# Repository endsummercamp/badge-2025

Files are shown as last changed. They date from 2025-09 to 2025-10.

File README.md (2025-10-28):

# badge-2025

Repository containing the schematics for the flex PCB badge distributed at ESC{21}.

The schematics are licensed under the CERN OHL S v2 license.

The badge has been designed by [Jacopo Franco](https://www.jacopofranco.com/), that we thank for the effort in making this literal show of force a reality ;)

Special thanks to [Kezi](https://github.com/Kezii), [Kowalski](https://github.com/kowalski7cc), [K3lite](https://github.com/k3lite) & [Baobots](https://github.com/baobots) for the efforts spent into debugging & flashing all of them during the camp.

And for going the extra mile and designing a custom case that solves many assembly issues, a very felt thanks to [k0bld](https://github.com/k0bld).

<video src="https://github.com/user-attachments/assets/acb0492f-e134-4207-b74a-9145ce9de10b"
       autoplay
       loop
       muted
       playsinline
       width="600">
  Your browser does not support the video tag.
</video>

---

# Badge Instructions

## Assembly

* The badge must be folded into position.
* To keep it fixed, we recommend using **UV glue**, **superglue**, or **thin double-sided tape**.
* **Do not solder directly** onto the PET substrate — this is very challenging, even with bismuth low-temperature solder.

## Flashing
**USB communication is not supported** — the port is for charging only.
To flash the badge the first time, make use of the UART and the power pins as below.




### USB-C Connector

* The USB-C must also be folded.
* Align the tab with the solid line located after the resistors.
* With the **copper contacts facing outward**, insert the connector into a male USB Type-C cable.


---

## Charging
* There are no LEDs to indicate charging progress. The charger is however guaranteed to fully charge the battery in 2.5h. The battery is fully protected and the charger has multiple overcurrent, overvoltage and temperature protections. It can trickle-charge.
* Battery life is approximately 4h with the "All sides music" profile and the WiFi radio at 8.5dBm.
* An **interrupt pin** connected to the charger will change state during charging. You will have to implement it yourself.

---

## Firmware

* The badge ships with the **WLED firmware** by default.
* * Firmware updates can be done via **WLED OTA** or the **Serial pads**.
* To connect:

  1. Connect to the Wi-Fi network:

     ```text
     SSID: wled-ap  
     Password: wled1234
     ```
  2. Open the address in your browser:

     ```text
     4.3.2.1
     ```

---

## Pinout

```text
Charger status:       GPIO 10
Battery voltage:      Analog GPIO 3 (divider only enabled when LED MOSFET is ON)
LEDs MOSFET:          GPIO 4
LED data:             GPIO 8
I²C SDA:              GPIO 7
I²C SCL:              GPIO 6
Touch button 1:       GPIO 0
Touch button 2:       GPIO 1
```

---

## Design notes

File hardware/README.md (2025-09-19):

ESC 2025 Badge

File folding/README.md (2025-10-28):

# Folding Instructions for the BadgESC{21} Badge

These are the instructions for folding the **BadgESC{21} Badge** into its final cube shape.
Use a **plastic card** or another thin, flat object to achieve tight bends on the PET plastic substrate. It may also be possible to mold the shape by gently warming the material, although this method has not been tested.

To secure the folded parts, use **UV glue**, **superglue**, or another strong adhesive.

---

## Step 1: Initial Positioning

PXL\_20251021\_200502498

1. Place the badge on a flat surface with the components **facing up**.
2. Bend the **USB connector flap** by aligning its edge with the **solid white line** located near the set of **small resistors**, **not** the large ones.
3. The large resistors are not connected to any circuit. They are present only to provide structural thickness for engaging the USB Type-C connector’s locking mechanism.

---

## Step 2: Power Switch and Battery Test

PXL\_20251021\_200546398

1. Ensure the **power slide switch** lever is positioned **outside the white silkscreen**, which indicates the badge is powered **off**.
2. Insert the battery and briefly **test the badge** by toggling the power switch.

---

## Step 3: Preparing for Folding

PXL\_20251021\_201041561
PXL\_20251021\_201408873

1. **Remove the battery** before proceeding.
2. Begin folding the badge along the **solid silkscreen lines** using a **flat, thin piece of plastic** to help create sharp bends.

---

## Step 4: Folding the Top

PXL\_20251021\_201714334

Continue folding the upper section of the badge carefully, ensuring all edges align properly.

---

## Step 5: Gluing the Structure

PXL\_20251021\_203347326

This is the most delicate part of the assembly.
Apply **small drops of glue** to the sides while maintaining the cube shape. You can use your **fingers** or **tape** to hold the parts in place while the glue sets.

---

## Step 6: Final Assembly

PXL\_20251028\_121333355

After the glue cures, the badge should form a stable cube-like structure as shown above.

Your **BadgESC{21} Badge** is now ready for use.

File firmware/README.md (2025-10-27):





The badge USB is physically unstable because of very tight tolerances in the port.
Please notice the points used to flash the badge in the picture above. You will need some thin-tip probes.

The .bin file is all you need. It's a 1:1 dump of the internal memory, containing WLED and all its settings. Feel free to flash it and then recompile a fresh new version.

## How to flash the first time
Go into the legacy directory, download the bin, then using esptool:
```
esptool.py --port=/dev/ttyUSB0 write-flash 0x0 backup.bin
```

---

# Recompiling the Firmware for BadgESC{21}

If you wish to recompile the WLED firmware yourself to customize features or update configurations, follow the instructions below.

## Steps to Recompile

1. Open the official WLED Web Compiler:
   [https://wled-compile.github.io/](https://wled-compile.github.io/)

2. Click **Load configuration from a file**.

3. From your computer, select the configuration file:
   `WLED_compile_dd_mm_yyyy_BadgESC{21}.json`

4. Click **Regenerate** to rebuild the firmware using the provided configuration.

5. After regeneration, you may customize and compile your firmware as required.

After compilation, download the resulting `.bin` file and flash it to your device following the standard WLED installation procedure.

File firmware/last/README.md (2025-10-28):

# 🔧 Flashing and Configuring WLED Firmware for BadgESC{21}

## 1. Flashing Firmware

First, flash the `.bin` file:

Flashing firmware example

---

### 1.1 Connect to Access Point (AP)

Since the firmware does not yet have your Wi-Fi credentials, the badge will create its own access point (AP).
Connect to it using the following information:

* **SSID:** `WLED-AP`
* **Password:** `wled1234`

---

## 2. Upload Configuration

Once connected to the device, find its IP address and navigate there.

1. At the top of the page, click **Config** → **Security & Updates**.
2. Scroll down until you reach **Backup & Restore** and **Restore presets**.
3. Upload the preset file:

   * `wled_presets_BadgESC{21}.json`
     *(Be sure to press **Upload** after selecting the file.)*
4. Next, in the **Restore configuration** section, select and upload the file:

   * `wled_cfg_BadgESC{21}.json`
5. Wait approximately **10 seconds**, then **toggle the power switch** to perform a full reboot.

---

### 2.1 Reconnect and Final Setup

After rebooting:

1. Reconnect to the Access Point `WLED-AP`.
2. 🔗 **[http://badgesc.local](http://badgesc.local)**
3. Navigate again to **Config → Wi-Fi Setup**.
4. Enter your local Wi-Fi network credentials to connect the badge to your home network.

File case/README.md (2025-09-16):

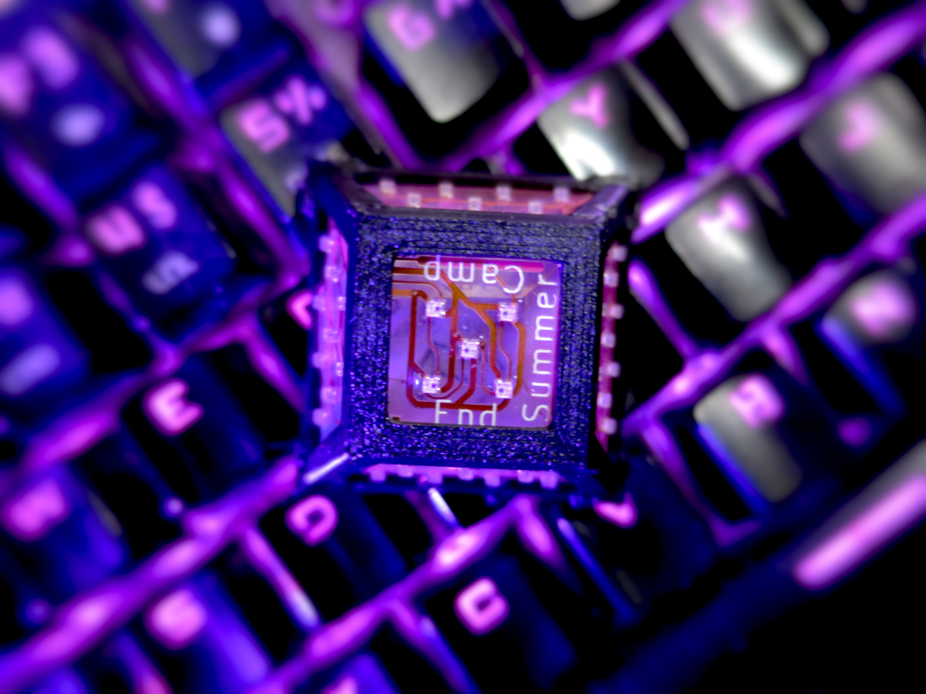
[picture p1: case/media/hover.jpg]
hover


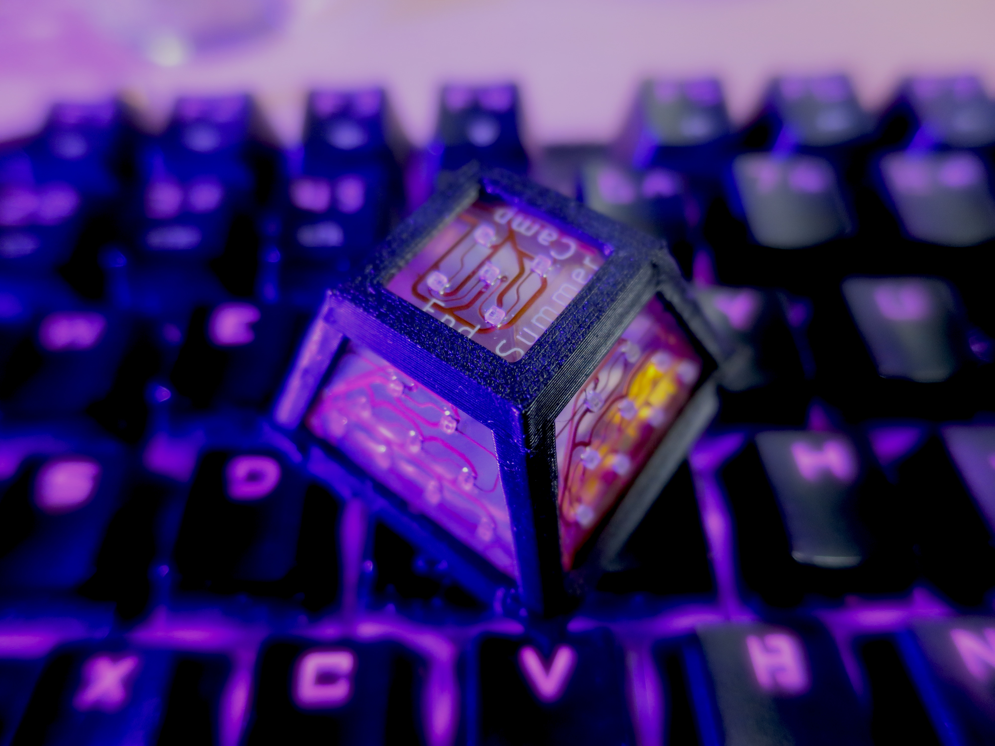
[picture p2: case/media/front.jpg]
front


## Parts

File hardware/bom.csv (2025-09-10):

Designator | Footprint | Quantity | Value | LCSC Part #
ANT2 | ANT-SMD_6P-L1.6-W0.8-P1.20-1 | 1 | ANT016008LCS2442MA | C76585
C1, C2, C3, C4 | CAP-SMD_BD4.0-L4.3-W4.3-LS5.1-FD | 4 | 126RV0140
C11, C12, C19, C9 | 0603 | 4 | 10uF
C13, C15, C20, C21, C7 | 0402 | 5 | 100nF
C14, C16, C23, C24, C31, C5, C8 | 0402 | 7 | 2.2uF
C17 | 0402 | 1 | 2.2uF | C12530
C18, C22 | 0402 | 2 | 15pF | C1548
C25 | 0402 | 1 | 10nF | C15195
C26 | 0402 | 1 | 100nF | C1525
C27 | 0402 | 1 | 1.1pF | C88920
C28 | 0402 | 1 | 2.3pF | C2190124
C6 | 0402 | 1 | 10nF
CN1 | CONN-SMD_2P-P1.20_781710002 | 1 | 781710002 | C505023
L1 | 0402 | 1 | 2.0nH | C76769
L4 | 0402 | 1 | 24nH | C404641
LED1, LED10, LED11, LED12, LED13, LED14, LED15, LED16, LED17, LED18, LED19, LED2, LED20, LED21, LED22, LED23, LED24, LED25, LED26, LED27, LED28, LED29, LED3, LED30, LED31, LED32, LED33, LED34, LED35, LED36, LED37, LED38, LED39, LED4, LED40, LED41, LED42, LED43, LED5, LED6, LED7, LED8, LED9 | LED-SMD_4P-L1.0-W1.0-TL_XL-1010RGBC-WS2812B | 43 | XL-1010RGBC-WS2812B
Q1 | SOT-23 | 1 | CJ3407 | C15903
Q2 | SOT-723 | 1 | SSM3K15AMFV,L3F(T
R1, R11, R2, R3, R5, R6 | 0402 | 6 | 5.1k | C25905
R10, R14, R21, R23, R4, R8 | 0402 | 6 | 100k | C25741
R13, R17, R18, R19, R20, R25 | 0603 | 6 | 49.9r | C23185
R16, R7, R9 | 0402 | 3 | 10k | C25744
SW1 | SW-TH_MSK12C02 | 1 | MSK12CO2-SZ
U1 | LGA-12_L2.0-W2.0-P0.50-BL | 1 | LIS2DH12TR
U2 | SOT-23-5_L2.9-W1.6-P0.95-LS2.8-TL | 1 | LGS4084HB5-4.35 | C20618071
U3 | QFN-32-1EP_5x5mm_P0.5mm_EP3.45x3.45mm | 1 | ESP32-C3 | C2858491
U4 | SOT-23-5_L3.0-W1.7-P0.95-LS2.8-BR | 1 | LW5233A23E | C20630437
U5 | SENSOR-SMD_ICS-43432 | 1 | ICS-43432 | C574021
Y1 | Crystal_SMD_2016-4Pin_2.0x1.6mm | 1 | 40MHz 10ppm 8pf | C2835990

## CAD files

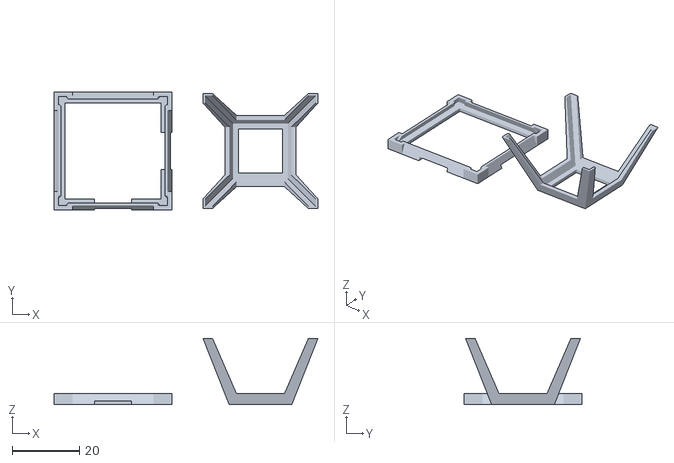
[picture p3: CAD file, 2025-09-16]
case/badge_case.stl
78.8 x 35.2 x 19.8

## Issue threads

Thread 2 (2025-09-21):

PCB assembly quality control not passed

Blaster1920, 2025-09-21:
We noticed an high amount of failures among the badges.
Upon inspection, at least a whole panel has been soldered with a subpar quality.
Follow pictures under the microscope.

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

Blaster1920, 2025-09-21:
The X-Ray views provided by JLC focusing on the accelerometer package.

[1.bmp](https://github.com/user-attachments/files/22453529/1.bmp)
[2.bmp](https://github.com/user-attachments/files/22453521/2.bmp)
[3.bmp](https://github.com/user-attachments/files/22453525/3.bmp)
[4.bmp](https://github.com/user-attachments/files/22453530/4.bmp)
[5.bmp](https://github.com/user-attachments/files/22453528/5.bmp)
[6.bmp](https://github.com/user-attachments/files/22453527/6.bmp)
[7.bmp](https://github.com/user-attachments/files/22453524/7.bmp)
[8.bmp](https://github.com/user-attachments/files/22453526/8.bmp)
[9.bmp](https://github.com/user-attachments/files/22453522/9.bmp)
[10.bmp](https://github.com/user-attachments/files/22453523/10.bmp)

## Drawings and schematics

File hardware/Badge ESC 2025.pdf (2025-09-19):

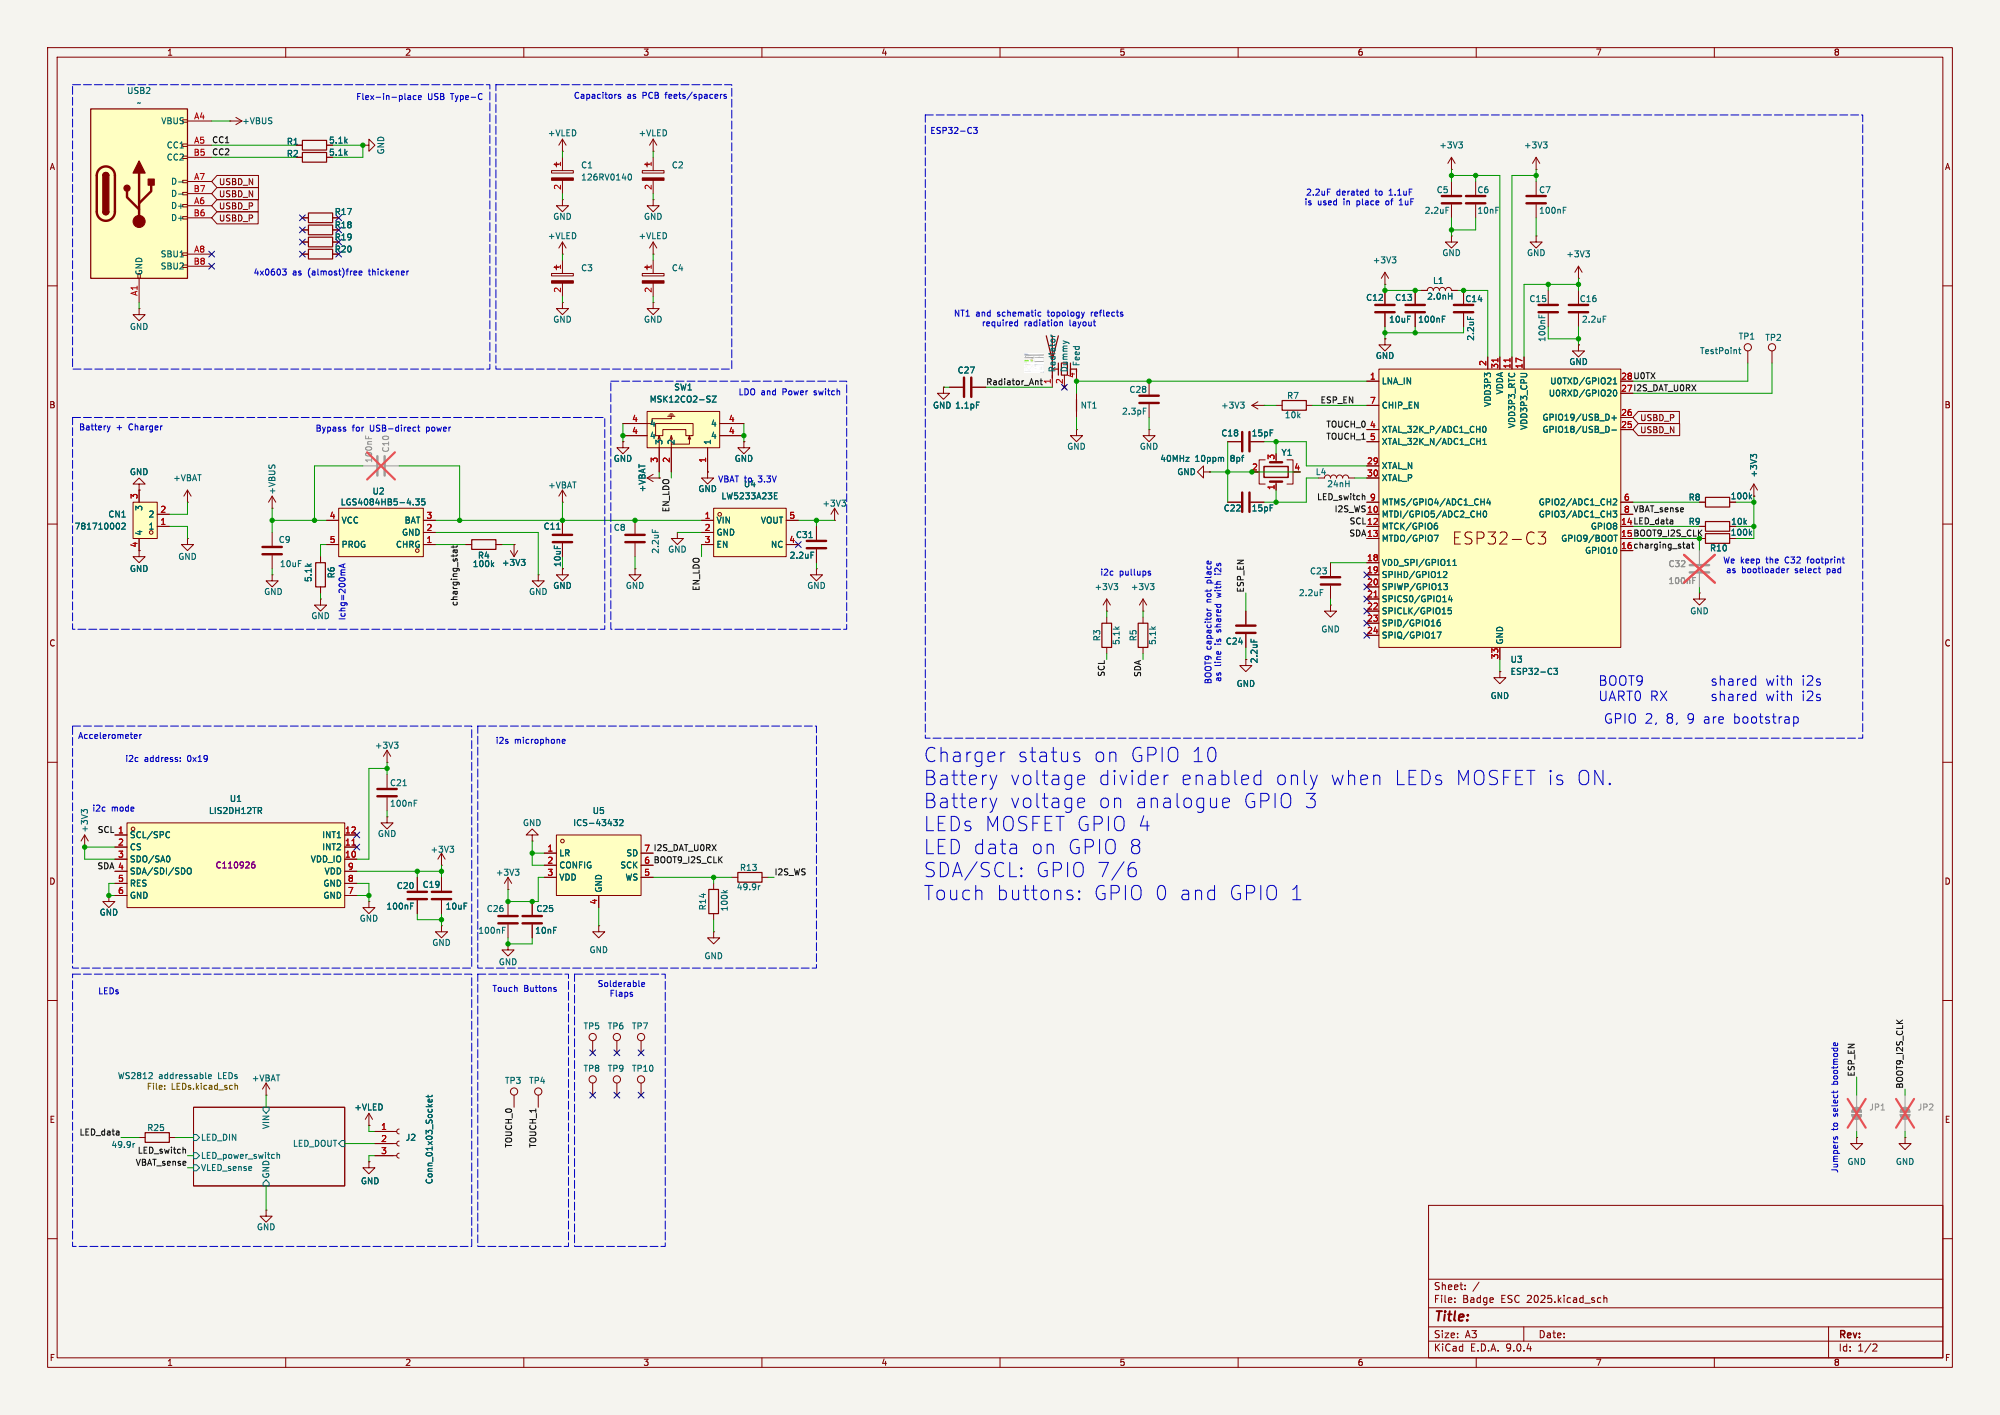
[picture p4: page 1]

1 2 C3 GND GND GND A1 VBUS A4 CC1 A5 CC2 B5 D- A7 D- B7 D+ A6 D+ B6 SBU1 A8 SBU2 B8 USB2 ~

2 VDDA 31 GND 33 VDD3P3_RTC 11 VDD3P3_CPU 17 U0TXD/GPIO21 28 U0RXD/GPIO20 27 GPIO19/USB_D+ 26 GPIO18/USB_D- 25 GPIO2/ADC1_CH2 6 GPIO3/ADC1_CH3 8 GPIO8 14 GPIO9/BOOT 15 GPIO10 16 U3ESP32-C3 +VBAT GND R14 100k

2 VDDA 31 GND 33 VDD3P3_RTC 11 VDD3P3_CPU 17 U0TXD/GPIO21 28 U0RXD/GPIO20 27 GPIO19/USB_D+ 26 GPIO18/USB_D- 25 GPIO2/ADC1_CH2 6 GPIO3/ADC1_CH3 8 GPIO8 14 GPIO9/BOOT 15 GPIO10 16 GND GND GND GND

4 SD 7 SCK 6 WS 5+VBAT GND GND GND U4
J2 Conn_01x03_Socket 1

Battery voltage divider enabled only when LEDs MOSFET is ON.
Battery voltage on analogue GPIO 3
LEDs MOSFET GPIO 4
LED data on GPIO 8
SDA/SCL: GPIO 7/6
Touch buttons: GPIO 0 and GPIO 1

SCL/SPC 1 CS 2 SDO/SA0 3 SDA/SDI/SDO 4 RES 5 GND 6
INT2 11 VDD_IO 10 VDD 9 GND 8 GND 7 GND

C110926 SCL/SPC 1 CS 2 SDO/SA0 3 SDA/SDI/SDO 4 RES 5 GND 6

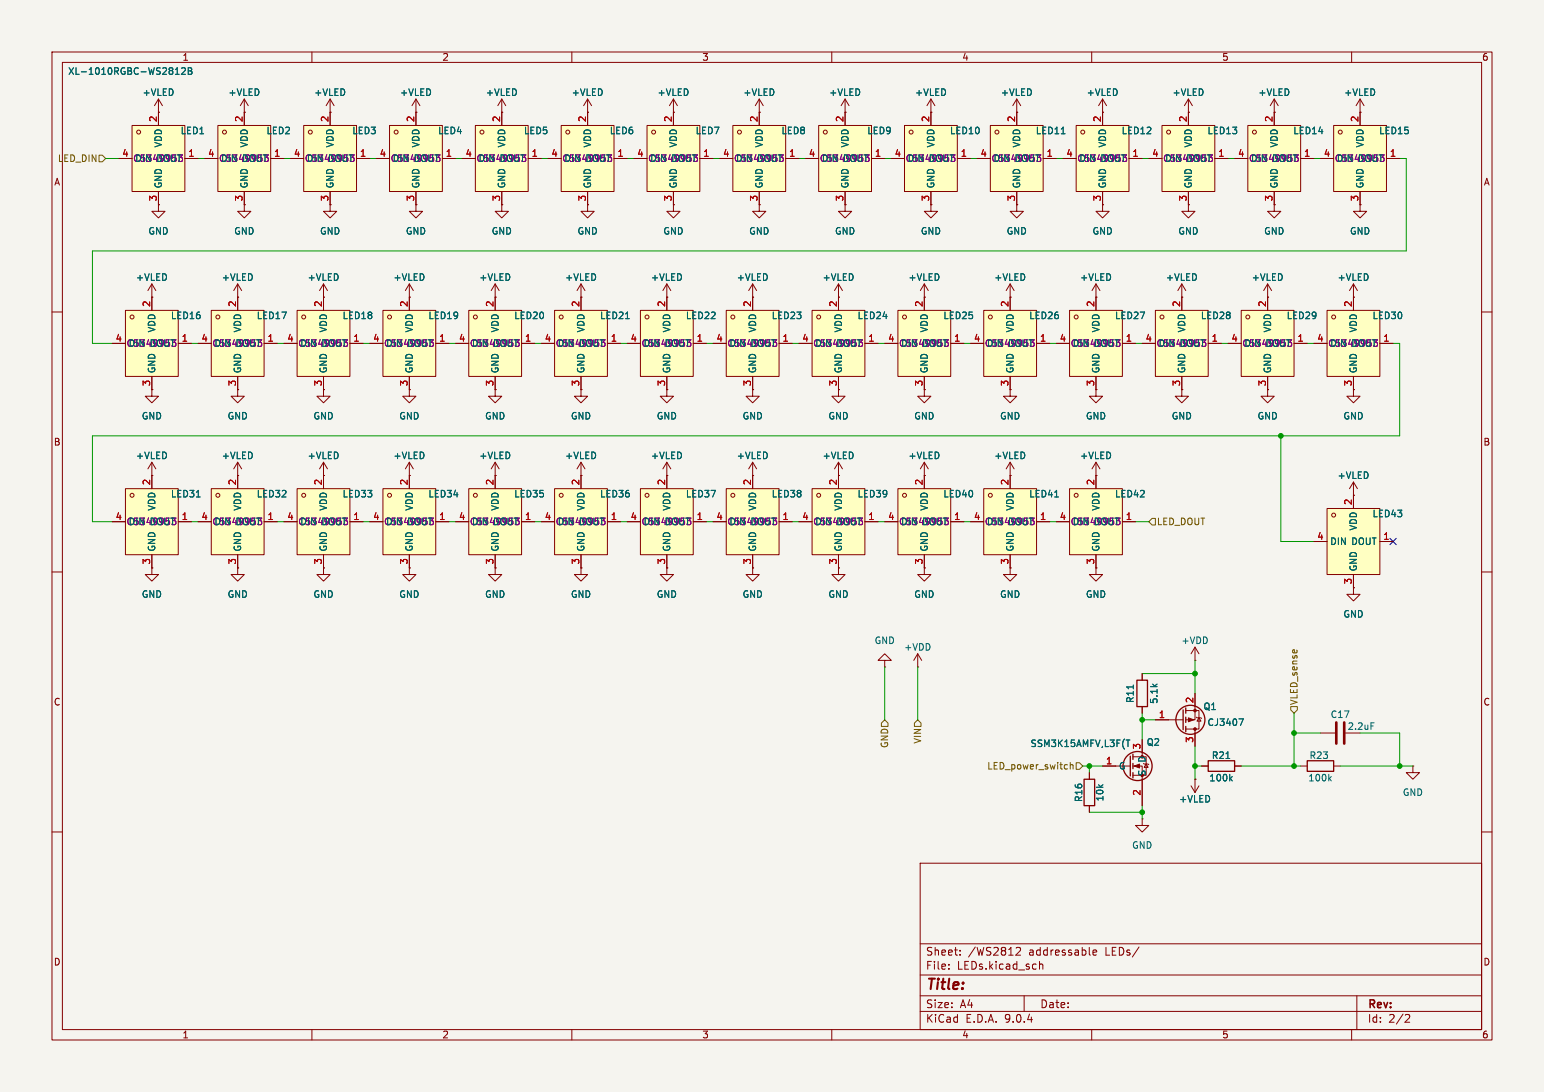
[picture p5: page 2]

3 DOUT 1 +VLED +VLED +VLED

3 DOUT 1 +VLED +VLED GND

3 DOUT 1 GND GND GND

3 DOUT 1 +VLED GND GND

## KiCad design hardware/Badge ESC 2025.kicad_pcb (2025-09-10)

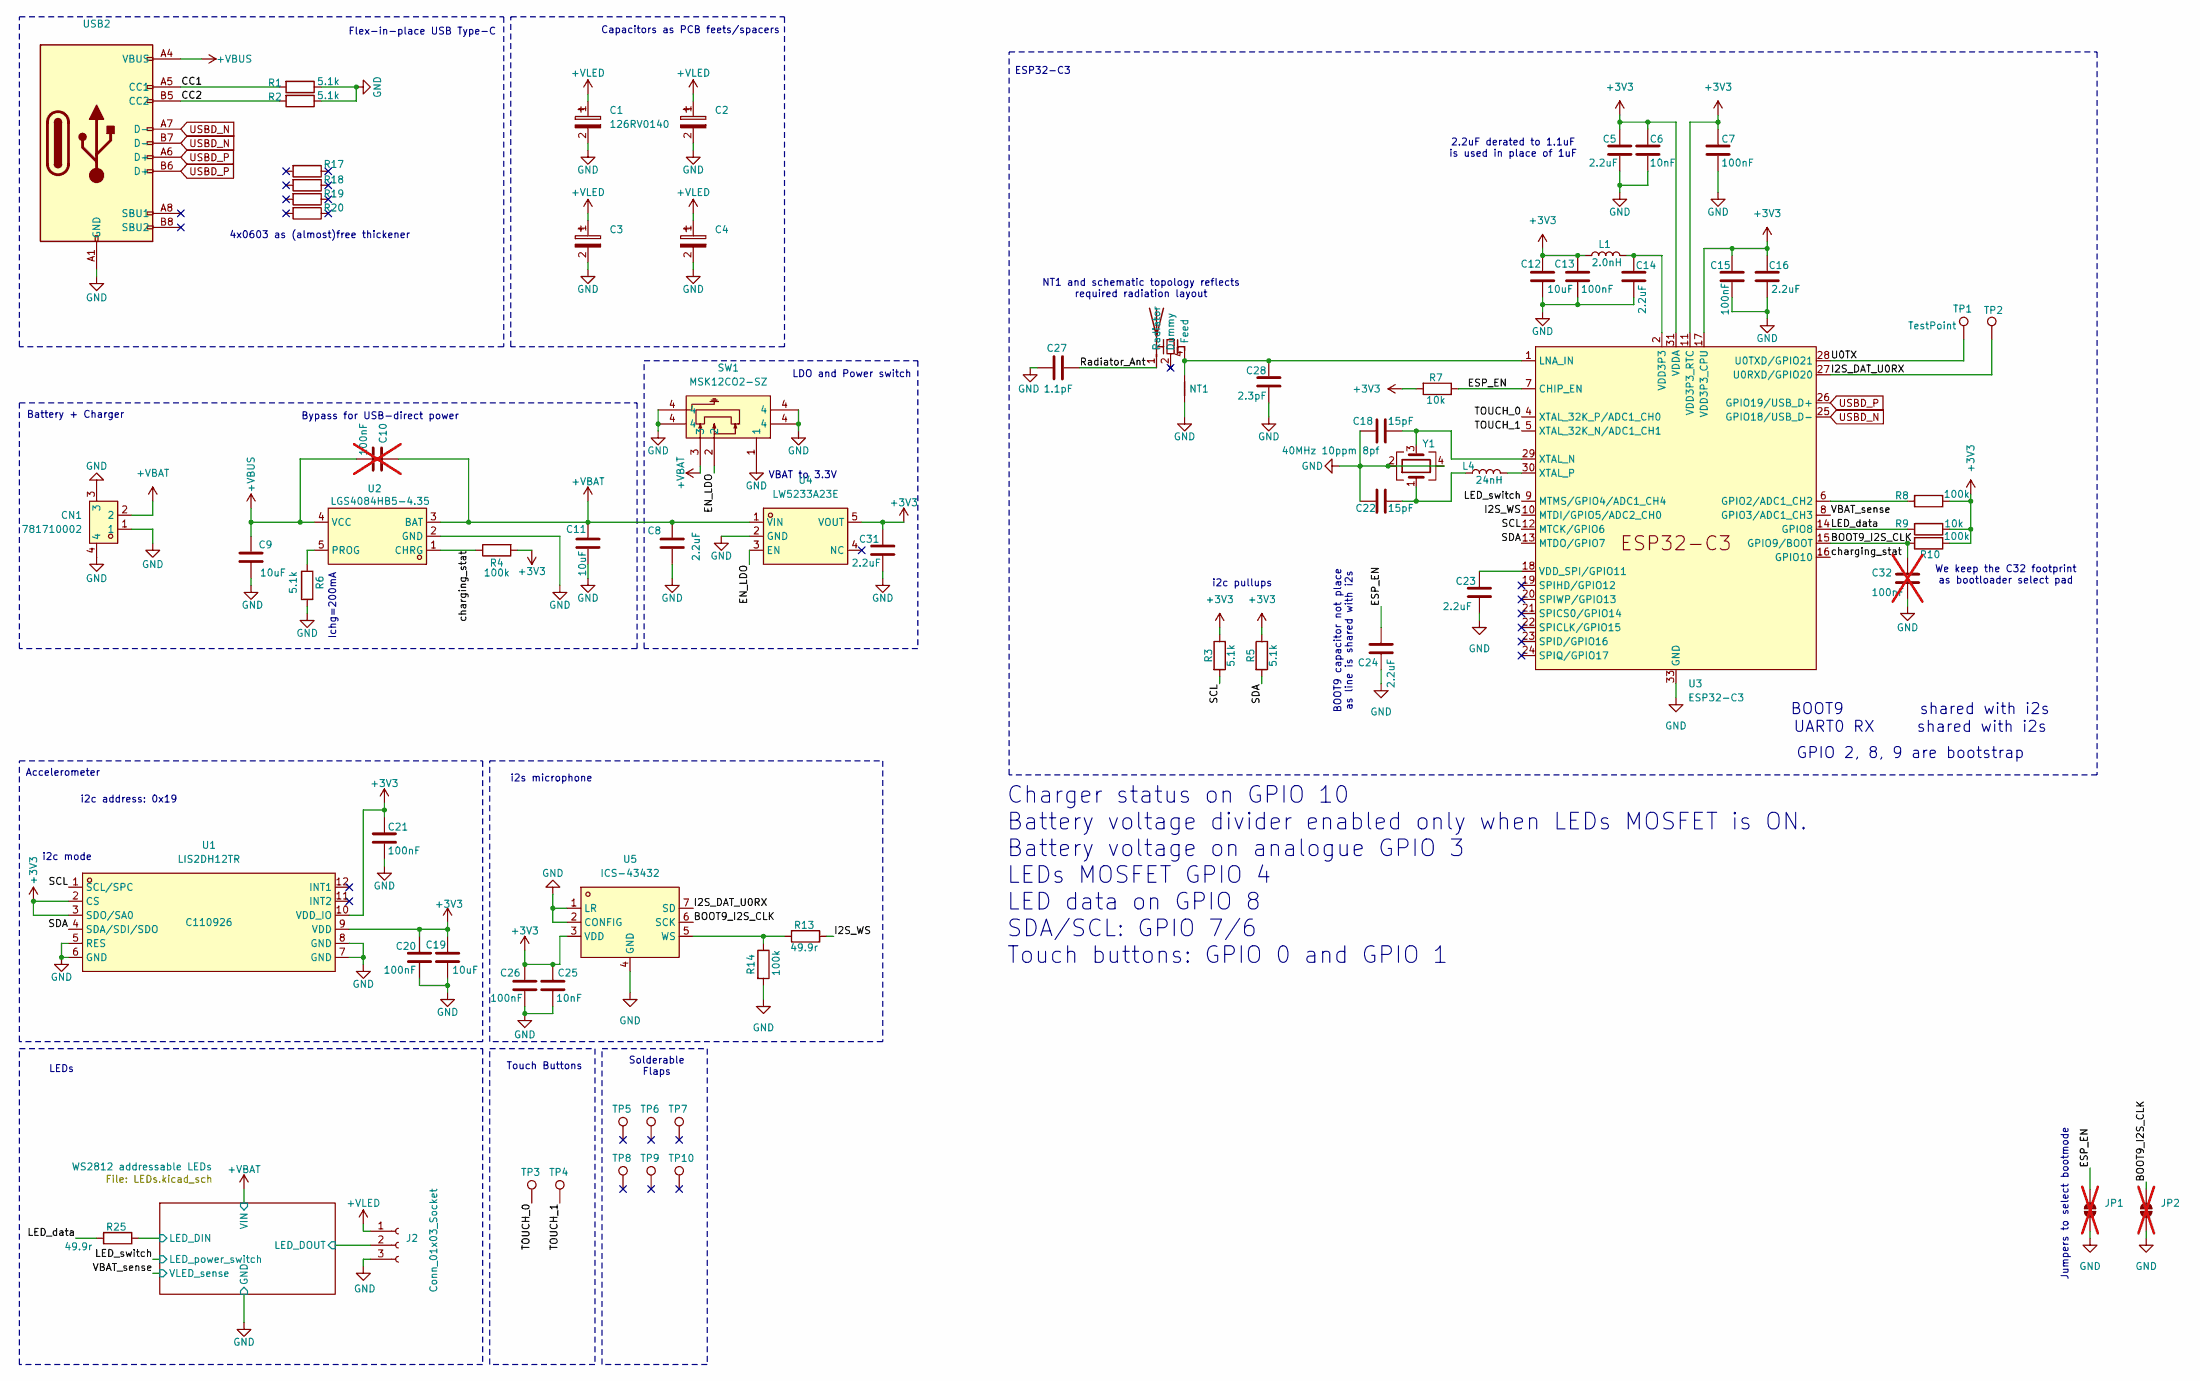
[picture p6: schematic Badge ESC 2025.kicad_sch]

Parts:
ANT2: ANT016008LCS2442MA; ANT-SMD_6P-L1.6-W0.8-P1.20-1; LCSC C76585
C1, C2, C3, C4: 126RV0140; CAP-SMD_BD4.0-L4.3-W4.3-LS5.1-FD; LCSC C7461271
C5, C8, C14, C16, C23, C24, C31: 2.2uF; C_0402_1005Metric; LCSC C12530
C6, C25: 10nF; C_0402_1005Metric; LCSC C15195
C7, C13, C15, C20, C21, C26: 100nF; C_0402_1005Metric; LCSC C1525
C9, C11, C12, C19: 10uF; C_0603_1608Metric; LCSC C19702
C10, C32: 100nF; C_0402_1005Metric; LCSC C1525; not fitted
C18, C22: 15pF; C_0402_1005Metric; LCSC C1548
C27: 1.1pF; C_0402_1005Metric; LCSC C88920
C28: 2.3pF; C_0402_1005Metric; LCSC C2190124
CN1: 781710002; CONN-SMD_2P-P1.20_781710002; LCSC Part C505023
J2: Conn_01x03_Socket; SolderJumper-3_P1.3mm_Open_RoundedPad1.0x1.5mm_NumberLabels
JP1, JP2: SolderJumper_2_Open; SolderJumper-2_P1.3mm_Open_Pad0.5x0.5mm; not fitted
L1: 2.0nH; L_0402_1005Metric; LCSC C76769
L4: 24nH; L_0402_1005Metric; LCSC C404641
NT1: NetTie_2; net_tie_2pins_0.2
R1, R2, R3, R5, R6: 5.1k; R_0402_1005Metric; LCSC C25905
R4, R8, R10, R14: 100k; R_0402_1005Metric; LCSC C25741
R7, R9: 10k; R_0402_1005Metric; LCSC C25744
R13, R17, R18, R19, R20, R25: 49.9r; R_0603_1608Metric; LCSC C23185
SW1: MSK12CO2-SZ; SW-TH_MSK12C02; LCSC C2681568
TP1, TP2: TestPoint; TestPoint_Pad_D1.0mm
TP3, TP4: TestPoint; Touch_pad_ESC
TP5, TP6, TP7, TP8, TP9, TP10: Solder_flap; Solder_flap_ESC
U1: LIS2DH12TR; LGA-12_L2.0-W2.0-P0.50-BL; LCSC C110926
U2: LGS4084HB5-4.35; SOT-23-5_L2.9-W1.6-P0.95-LS2.8-TL; LCSC C20618071
U3: ESP32-C3; QFN-32-1EP_5x5mm_P0.5mm_EP3.45x3.45mm; LCSC C2858491
U4: LW5233A23E; SOT-23-5_L3.0-W1.7-P0.95-LS2.8-BR; LCSC Part C20630437
U5: ICS-43432; SENSOR-SMD_ICS-43432; LCSC C574021
USB2: USB_Type_C_FlexPCB_Fold
Y1: 40MHz 10ppm 8pf; Crystal_SMD_2016-4Pin_2.0x1.6mm; LCSC C2835990

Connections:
+3V3: C5.2, C6.1, C7.1, C12.1, C13.1, C15.1, C16.2, C19.1, C20.1, C21.1, C25.2, C26.2, C31.2, L1.1, R3.1, R4.2, R5.1, R7.2, R8.1, R9.1, R10.1, U1.2 (CS), U1.3 (SDO/SA0), U1.9 (VDD), U1.10 (VDD_IO), U3.11 (VDD3P3_RTC), U3.17 (VDD3P3_CPU), U3.31 (VDDA), U3.32 (VDDA), U4.5 (VOUT), U5.3 (VDD)
+VBAT: C8.1, C10.1, C11.1, CN1.2, SW1.3, U2.3 (BAT), U4.1 (VIN); also elsewhere on the board
+VBUS: C9.1, C10.2, U2.4 (VCC), USB2.A4 (VBUS), USB2.A9 (VBUS), USB2.B4 (VBUS), USB2.B9 (VBUS)
+VLED: C1.1, C2.1, C3.1, C4.1, J2.1; also elsewhere on the board
/BOOT9_I2S_CLK: C32.1, JP2.2 (B), R10.2, U3.15 (GPIO9/BOOT), U5.6 (SCK)
/CC1: R1.2, USB2.A5 (CC1)
/CC2: R2.2, USB2.B5 (CC2)
/EN_LDO: SW1.2, U4.3 (EN)
/ESP_EN: C24.2, JP1.2 (B), R7.1, U3.7 (CHIP_EN)
/I2S_DAT_U0RX: TP2.1, U3.27 (U0RXD/GPIO20), U5.7 (SD)
/I2S_WS: R13.1, U3.10 (MTDI/GPIO5/ADC2_CH0)
/LED_data: R9.2, R25.2, U3.14 (GPIO8)
/LED_switch: U3.9 (MTMS/GPIO4/ADC1_CH4); also elsewhere on the board
/Radiator_Ant: ANT2.1 (Radiator), C27.1
/SCL: R3.2, U1.1 (SCL/SPC), U3.12 (MTCK/GPIO6)
/SDA: R5.2, U1.4 (SDA/SDI/SDO), U3.13 (MTDO/GPIO7)
/TOUCH_0: TP3.1, U3.4 (XTAL_32K_P/ADC1_CH0)
/TOUCH_1: TP4.1, U3.5 (XTAL_32K_N/ADC1_CH1)
/U0TX: TP1.1, U3.28 (U0TXD/GPIO21)
/VBAT_sense: U3.8 (GPIO3/ADC1_CH3); also elsewhere on the board
/WS2812 addressable LEDs/LED_DIN: R25.1; also elsewhere on the board
/WS2812 addressable LEDs/LED_DOUT: J2.2; also elsewhere on the board
/charging_stat: R4.1, U2.1 (CHRG), U3.16 (GPIO10)
GND: C1.2, C2.2, C3.2, C4.2, C5.1, C6.2, C7.2, C8.2, C9.2, C11.2, C12.2, C13.2, C14.2, C15.2, C16.1, C18.1, C19.2, C20.2, C21.2, C22.1, C23.1, C24.1, C25.1, C26.1, C27.2, C28.1, C31.1, C32.2, CN1.1, CN1.3, CN1.4, J2.3, JP1.1 (A), JP2.1 (A), NT1.1, R1.1, R2.1, R6.1, R14.2, SW1.1, SW1.4, U1.5 (RES), U1.6 (GND), U1.7 (GND), U1.8 (GND), U2.2 (GND), U3.33 (GND), U4.2 (GND), U5.1 (LR), U5.2 (CONFIG), U5.4 (GND), USB2.A1 (GND), USB2.A12 (GND), USB2.B1 (GND), USB2.B12 (GND), Y1.2, Y1.4; also elsewhere on the board
unnamed: ANT2.4 (Feed), C28.2, NT1.2, U3.1 (LNA_IN)
unnamed: C14.1, L1.2, U3.2 (VDD3P3), U3.3 (VDD3P3)
unnamed: C22.2, L4.1, Y1.1
unnamed: R6.2, U2.5 (PROG)
unnamed: R8.2, U3.6 (GPIO2/ADC1_CH2)
unnamed: C23.2, U3.18 (VDD_SPI/GPIO11)
unnamed: C18.2, U3.29 (XTAL_N), Y1.3
unnamed: L4.2, U3.30 (XTAL_P)
unnamed: R13.2, R14.1, U5.5 (WS)
USBD_N: U3.25 (GPIO18/USB_D-), USB2.A7 (D-), USB2.B7 (D-)
USBD_P: U3.26 (GPIO19/USB_D+), USB2.A6 (D+), USB2.B6 (D+)

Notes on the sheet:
LEDs
4x0603 as (almost)free thickener
Bypass for USB-direct power
Solderable Flaps
NT1 and schematic topology reflects required radiation layout
Jumpers to select bootmode
Capacitors as PCB feets/spacers
i2c pullups
BOOT9 shared with i2s UART0 RX shared with i2s
Flex-in-place USB Type-C
Touch Buttons
Charger status on GPIO 10 Battery voltage divider enabled only when LEDs MOSFET is ON. Battery voltage on analogue GPIO 3 LEDs MOSFET GPIO 4 LED data on GPIO 8 SDA/SCL: GPIO 7/6 Touch buttons: GPIO 0 and GPIO 1
i2c address: 0x19
VBAT to 3.3V
Accelerometer
LDO and Power switch
We keep the C32 footprint as bootloader select pad
BOOT9 capacitor not place as line is shared with i2s
ESP32-C3
2.2uF derated to 1.1uF is used in place of 1uF
GPIO 2, 8, 9 are bootstrap
Ichg=200mA
i2s microphone
Battery + Charger
i2c mode

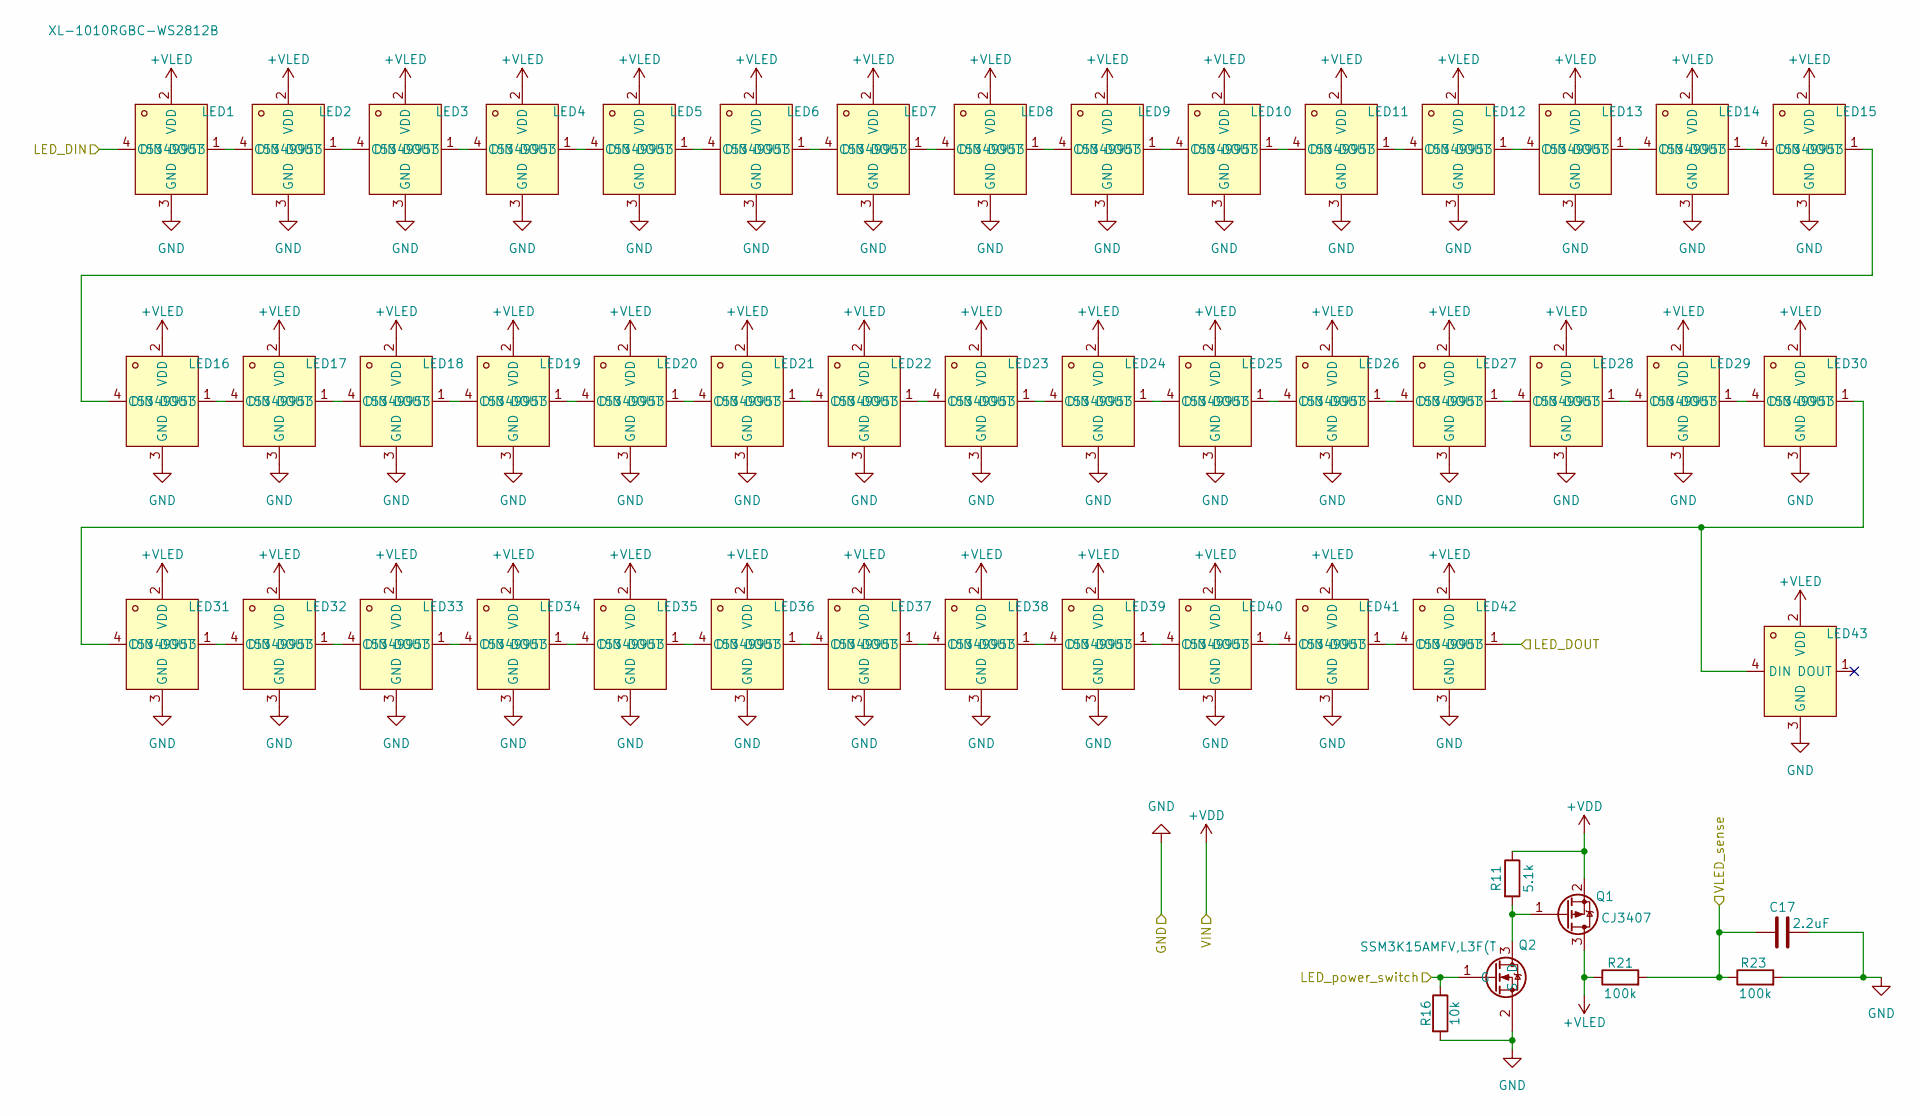
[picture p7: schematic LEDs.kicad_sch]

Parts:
C17: 2.2uF; C_0402_1005Metric; LCSC C12530
LED1, LED2, LED3, LED4, LED5, LED6, LED7, LED8, LED9, LED10, LED11, LED12, LED13, LED14, LED15, LED16, LED17, LED18, LED19, LED20, LED21, LED22, LED23, LED24, LED25, LED26, LED27, LED28, LED29, LED30, LED31, LED32, LED33, LED34, LED35, LED36, LED37, LED38, LED39, LED40, LED41, LED42, LED43: XL-1010RGBC-WS2812B; LED-SMD_4P-L1.0-W1.0-TL_XL-1010RGBC-WS2812B; LCSC C5349953
Q1: CJ3407; SOT-23; LCSC C15903
Q2: SSM3K15AMFV,L3F(T; SOT-723; LCSC C516857
R11: 5.1k; R_0402_1005Metric; LCSC C25905
R16: 10k; R_0402_1005Metric; LCSC C25744
R21, R23: 100k; R_0402_1005Metric; LCSC C25741

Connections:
+VBAT: Q1.2 (S), R11.1; also elsewhere on the board
+VLED: LED1.2 (VDD), LED2.2 (VDD), LED3.2 (VDD), LED4.2 (VDD), LED5.2 (VDD), LED6.2 (VDD), LED7.2 (VDD), LED8.2 (VDD), LED9.2 (VDD), LED10.2 (VDD), LED11.2 (VDD), LED12.2 (VDD), LED13.2 (VDD), LED14.2 (VDD), LED15.2 (VDD), LED16.2 (VDD), LED17.2 (VDD), LED18.2 (VDD), LED19.2 (VDD), LED20.2 (VDD), LED21.2 (VDD), LED22.2 (VDD), LED23.2 (VDD), LED24.2 (VDD), LED25.2 (VDD), LED26.2 (VDD), LED27.2 (VDD), LED28.2 (VDD), LED29.2 (VDD), LED30.2 (VDD), LED31.2 (VDD), LED32.2 (VDD), LED33.2 (VDD), LED34.2 (VDD), LED35.2 (VDD), LED36.2 (VDD), LED37.2 (VDD), LED38.2 (VDD), LED39.2 (VDD), LED40.2 (VDD), LED41.2 (VDD), LED42.2 (VDD), LED43.2 (VDD), Q1.3 (D), R21.1; also elsewhere on the board
/LED_switch: Q2.1 (G), R16.1; also elsewhere on the board
/VBAT_sense: C17.2, R21.2, R23.1; also elsewhere on the board
/WS2812 addressable LEDs/LED_DIN: LED1.4 (DIN); also elsewhere on the board
/WS2812 addressable LEDs/LED_DOUT: LED42.1 (DOUT); also elsewhere on the board
GND: C17.1, LED1.3 (GND), LED2.3 (GND), LED3.3 (GND), LED4.3 (GND), LED5.3 (GND), LED6.3 (GND), LED7.3 (GND), LED8.3 (GND), LED9.3 (GND), LED10.3 (GND), LED11.3 (GND), LED12.3 (GND), LED13.3 (GND), LED14.3 (GND), LED15.3 (GND), LED16.3 (GND), LED17.3 (GND), LED18.3 (GND), LED19.3 (GND), LED20.3 (GND), LED21.3 (GND), LED22.3 (GND), LED23.3 (GND), LED24.3 (GND), LED25.3 (GND), LED26.3 (GND), LED27.3 (GND), LED28.3 (GND), LED29.3 (GND), LED30.3 (GND), LED31.3 (GND), LED32.3 (GND), LED33.3 (GND), LED34.3 (GND), LED35.3 (GND), LED36.3 (GND), LED37.3 (GND), LED38.3 (GND), LED39.3 (GND), LED40.3 (GND), LED41.3 (GND), LED42.3 (GND), LED43.3 (GND), Q2.2 (S), R16.2, R23.2; also elsewhere on the board
unnamed: LED1.1 (DOUT), LED2.4 (DIN)
unnamed: LED2.1 (DOUT), LED3.4 (DIN)
unnamed: LED3.1 (DOUT), LED4.4 (DIN)
unnamed: LED4.1 (DOUT), LED5.4 (DIN)
unnamed: LED5.1 (DOUT), LED6.4 (DIN)
unnamed: LED6.1 (DOUT), LED7.4 (DIN)
unnamed: LED7.1 (DOUT), LED8.4 (DIN)
unnamed: LED8.1 (DOUT), LED9.4 (DIN)
unnamed: LED9.1 (DOUT), LED10.4 (DIN)
unnamed: LED10.1 (DOUT), LED11.4 (DIN)
unnamed: LED11.1 (DOUT), LED12.4 (DIN)
unnamed: LED12.1 (DOUT), LED13.4 (DIN)
unnamed: LED13.1 (DOUT), LED14.4 (DIN)
unnamed: LED14.1 (DOUT), LED15.4 (DIN)
unnamed: LED15.1 (DOUT), LED16.4 (DIN)
unnamed: LED16.1 (DOUT), LED17.4 (DIN)
unnamed: LED17.1 (DOUT), LED18.4 (DIN)
unnamed: LED18.1 (DOUT), LED19.4 (DIN)
unnamed: LED19.1 (DOUT), LED20.4 (DIN)
unnamed: LED20.1 (DOUT), LED21.4 (DIN)
unnamed: LED21.1 (DOUT), LED22.4 (DIN)
unnamed: LED22.1 (DOUT), LED23.4 (DIN)
unnamed: LED23.1 (DOUT), LED24.4 (DIN)
unnamed: LED24.1 (DOUT), LED25.4 (DIN)
unnamed: LED25.1 (DOUT), LED26.4 (DIN)
unnamed: LED26.1 (DOUT), LED27.4 (DIN)
unnamed: LED27.1 (DOUT), LED28.4 (DIN)
unnamed: LED28.1 (DOUT), LED29.4 (DIN)
unnamed: LED29.1 (DOUT), LED30.4 (DIN)
unnamed: LED30.1 (DOUT), LED31.4 (DIN), LED43.4 (DIN)
unnamed: LED31.1 (DOUT), LED32.4 (DIN)
unnamed: LED32.1 (DOUT), LED33.4 (DIN)
unnamed: LED33.1 (DOUT), LED34.4 (DIN)
unnamed: LED34.1 (DOUT), LED35.4 (DIN)
unnamed: LED35.1 (DOUT), LED36.4 (DIN)
unnamed: LED36.1 (DOUT), LED37.4 (DIN)
unnamed: LED37.1 (DOUT), LED38.4 (DIN)
unnamed: LED38.1 (DOUT), LED39.4 (DIN)
unnamed: LED39.1 (DOUT), LED40.4 (DIN)
unnamed: LED40.1 (DOUT), LED41.4 (DIN)
unnamed: LED41.1 (DOUT), LED42.4 (DIN)
unnamed: Q1.1 (G), Q2.3 (D), R11.2

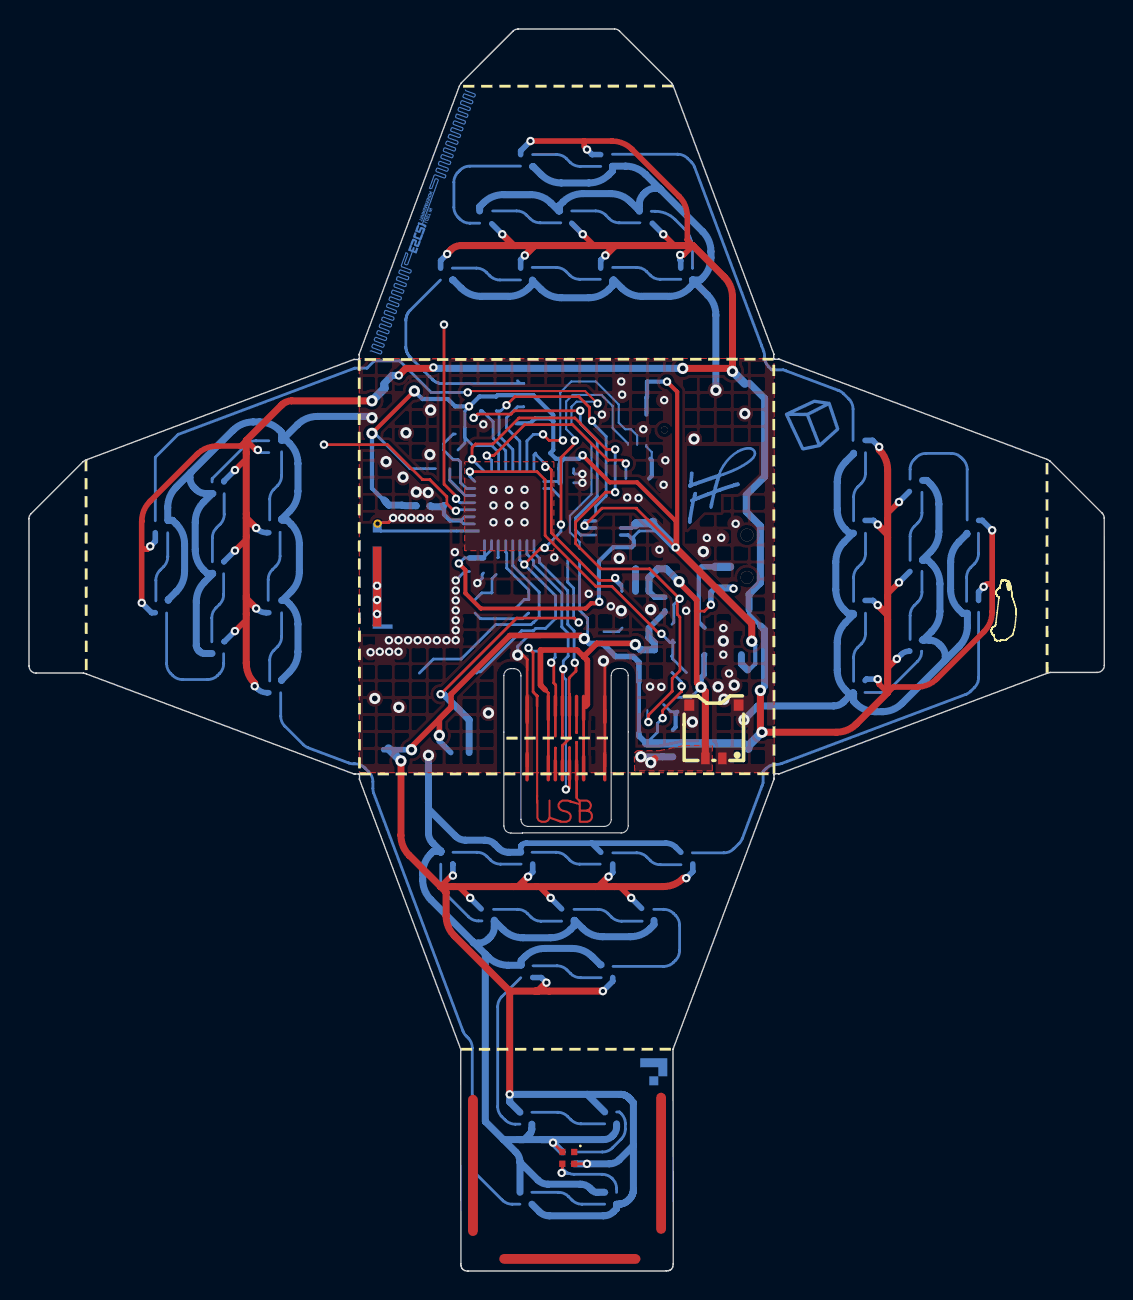
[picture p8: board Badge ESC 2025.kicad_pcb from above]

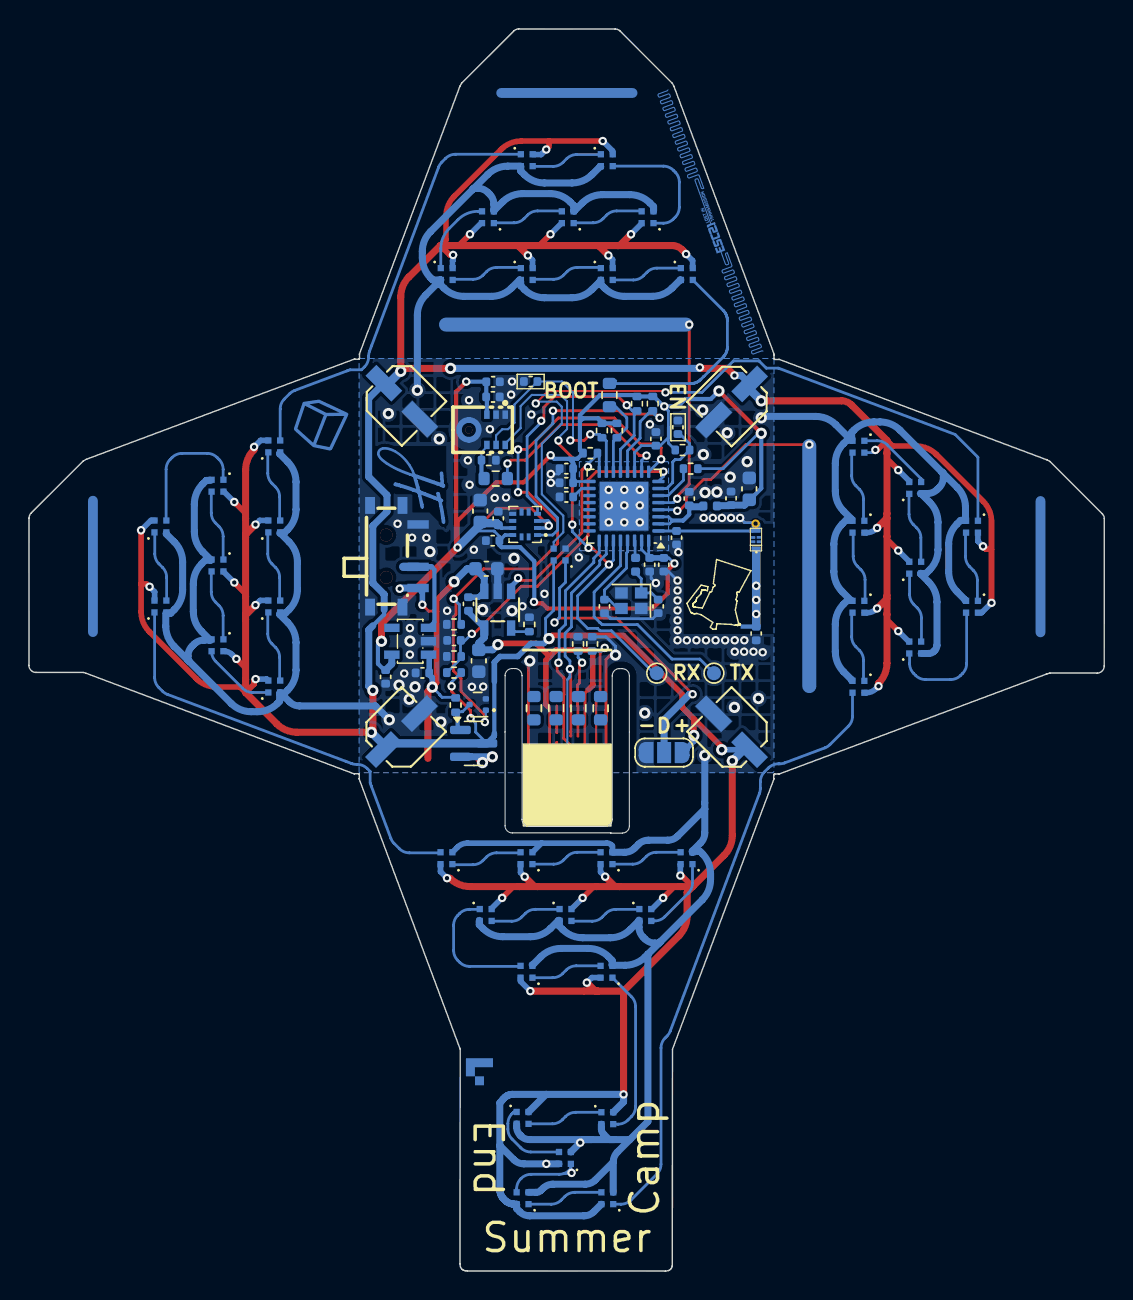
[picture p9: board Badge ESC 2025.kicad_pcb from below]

Board: 2 copper layers, 76.1 x 87.9 mm, 120 parts (113 on the bottom side), 77 nets.

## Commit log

2025-09-10 BOM + positions
    [bom.csv, positions.csv]
2025-09-10 add gerbers
    [Badge ESC 2025-B_Cu.gbl, Badge ESC 2025-B_Mask.gbs, Badge ESC 2025-B_Paste.gbp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]
2025-09-16 3d printable badge case
    [badge_case.stl]
2025-10-28 Update README with battery life details
    Added information about battery life with WiFi settings.
2025-10-28 Add README with folding instructions for BadgESC{21} Badge
    Added detailed folding instructions for the BadgESC{21} Badge, including steps for initial positioning, power switch testing, and final assembly.
2025-10-28 Add acknowledgment for k0bld's custom case design
    Added a thank you note for k0bld for designing a custom case.
2025-10-28 Revised wled connection IP
    Updated instructions for device connection and navigation.
